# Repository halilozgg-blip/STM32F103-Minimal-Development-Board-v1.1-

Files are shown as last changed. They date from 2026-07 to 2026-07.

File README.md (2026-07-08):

# STM32F103 Minimal Development Board (v1.1)
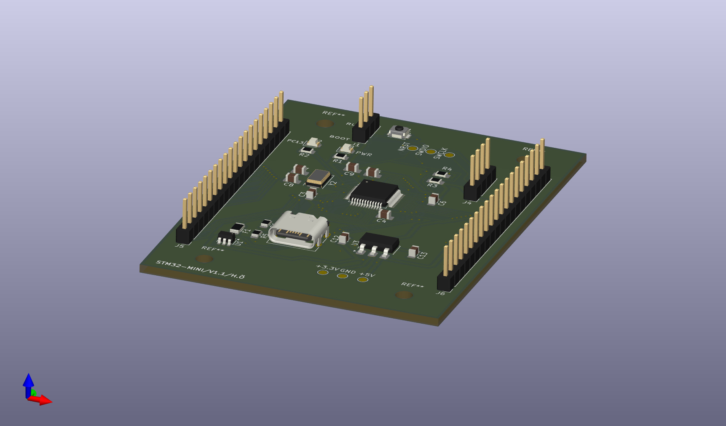
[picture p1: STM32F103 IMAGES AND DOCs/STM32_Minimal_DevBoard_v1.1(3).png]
Board 3D Render




##  Project Overview
This project is a custom-designed **STM32F103C8T6** development board created using **KiCad 9.0**. It provides a compact and reliable hardware platform for embedded software development, rapid prototyping, and educational projects.

The design focuses on clean power distribution, hardware protection, modular architecture, and debugging convenience while following recommended PCB design practices.

##  Design Goals
* **Reliable Hardware:** Design a stable and reusable STM32 development platform.
* **Easy Development:** Provide essential interfaces required for firmware development and debugging.
* **Good PCB Practices:** Follow clean schematic organization and PCB layout guidelines.
* **Open Source:** Make the project easy to understand, reproduce, and modify.

##  Key Features

###  Power & Protection
* **USB Type-C** Power Input.
* **USBLC6-2SC6** TVS diode for ESD protection on USB data lines.
* **500 mA** Resettable PTC Polyfuse for overcurrent protection.
* **AMS1117-3.3V** linear regulator providing a stable 3.3V supply.
* Decoupling capacitors placed according to STM32 hardware design recommendations.

###  Microcontroller Hardware
* **STM32F103C8T6** ARM Cortex-M3 microcontroller.
* External crystal oscillator.
* Hardware reset circuit.
* Pull-down resistor on `BOOT0` for reliable boot configuration.
* **SWD** programming and debugging interface.
* Clearly labeled test points for debugging and measurements.

###  Development Features
* User LED.
* User push button.
* GPIO expansion headers.
* Modular schematic hierarchy for easier maintenance and future expansion.

## 📂 Repository Structure
  ```text
STM32F103_Minimal_Development_Board_v1.1
│
├── HARDWARE/        # KiCad Project, Schematics, and PCB Layout
├── PRODUCTION/     # Gerber Files, Drill Files, and Manufacturing Outputs
└── STM32F103 IMAGES AND DOCS/
    ├── Schematic PDF, PCB Images
    ├── 3D Renders
    └── Project Documentation
  ```
#  Hardware Summary

| Component | Description |
| :--- | :--- |
| **MCU** | STM32F103C8T6 |
| **Core** | ARM Cortex-M3 |
| **Operating Voltage** | 3.3 V |
| **Power Input** | USB Type-C |
| **Debug Interface** | SWD |
| **PCB Design** | KiCad 9.0 |

##  Future Improvements
* USB communication support.
* Additional protection circuitry.
* Boot mode selection jumper.
* CAN interface.
* External SPI Flash & I²C EEPROM.
* Additional status indicators.

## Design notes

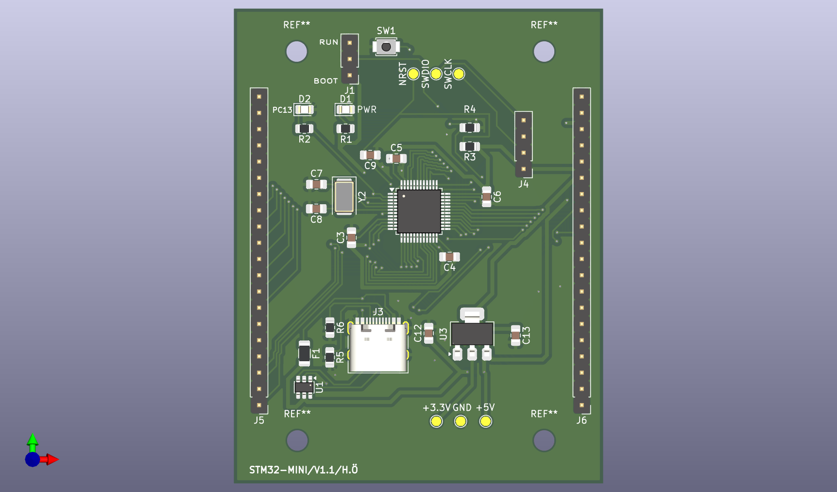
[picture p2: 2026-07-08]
STM32F103 IMAGES AND DOCs/STM32_Minimal_DevBoard_v1.1(1).png

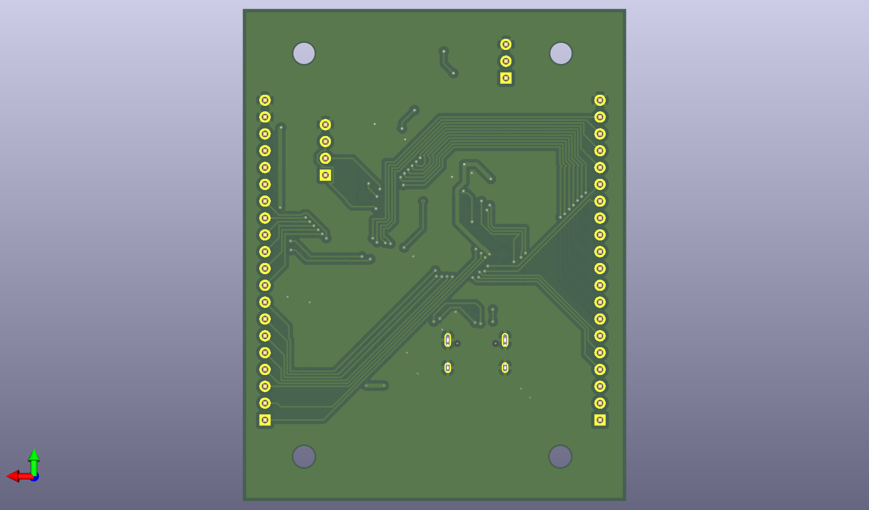
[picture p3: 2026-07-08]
STM32F103 IMAGES AND DOCs/STM32_Minimal_DevBoard_v1.1(2).png

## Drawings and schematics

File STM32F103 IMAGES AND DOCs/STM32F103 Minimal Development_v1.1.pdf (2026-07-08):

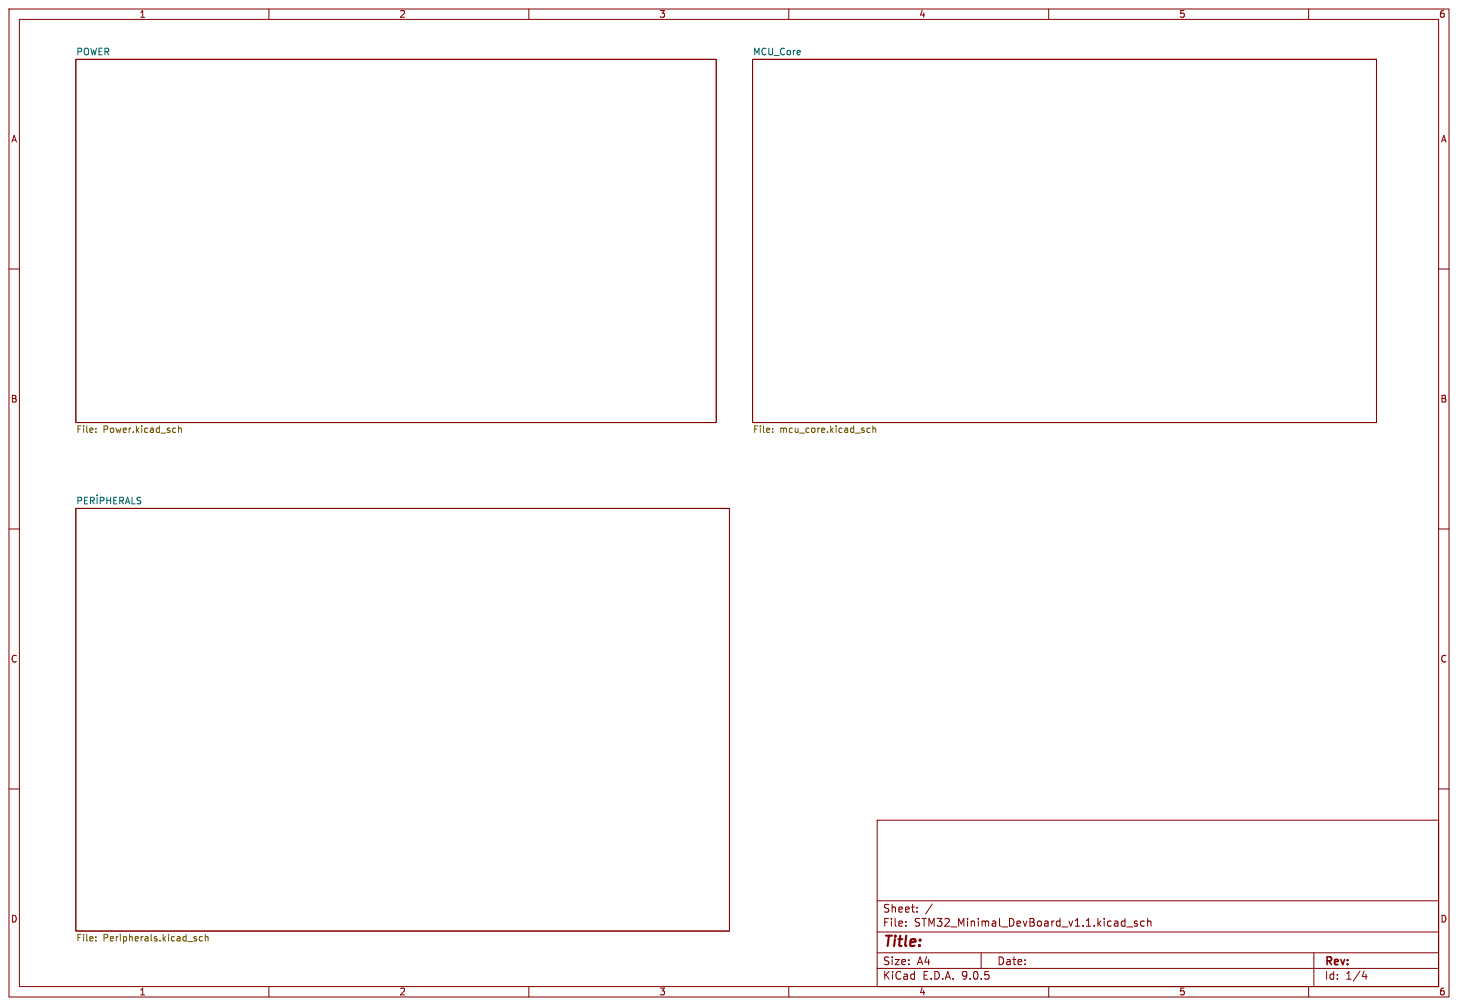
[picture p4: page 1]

Id: 1/4 Title: File: STM32_Minimal_DevBoard_v1.1.kicad_sch Sheet: /

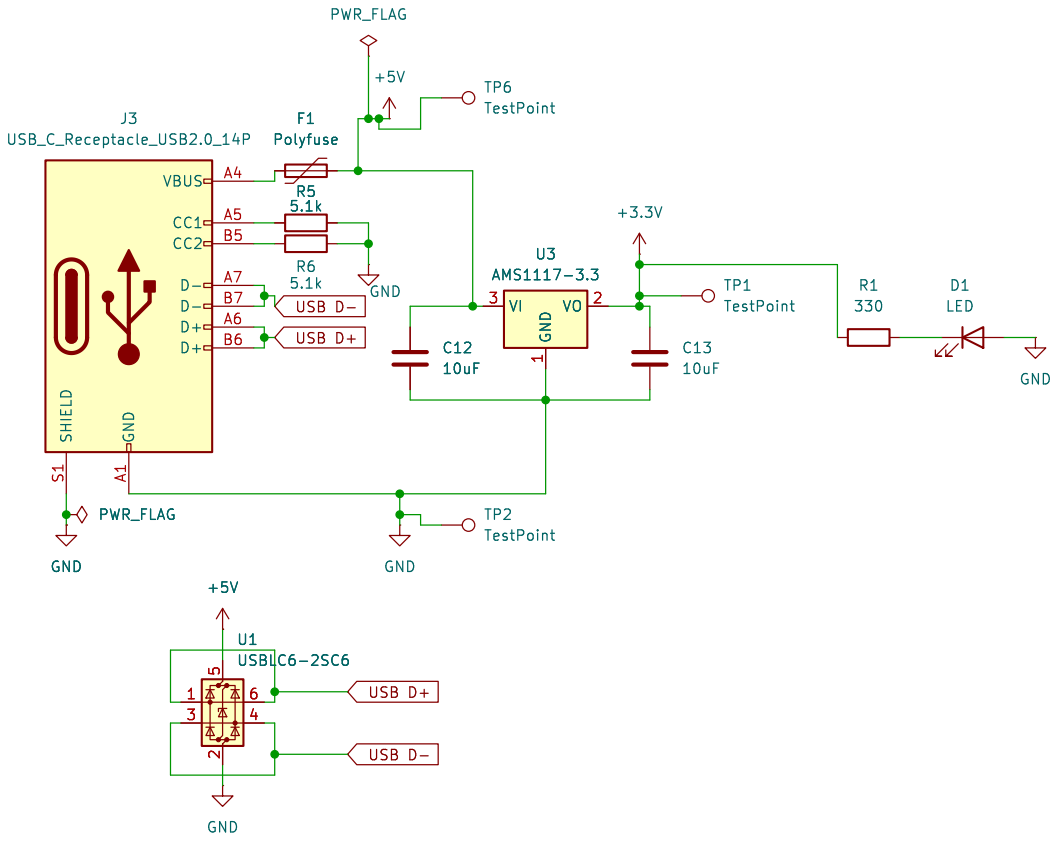
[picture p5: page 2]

330 USB D- USB D+ USB D+ USB D- GND

Id: 2/4 Title: File: Power.kicad_sch Sheet: /POWER/

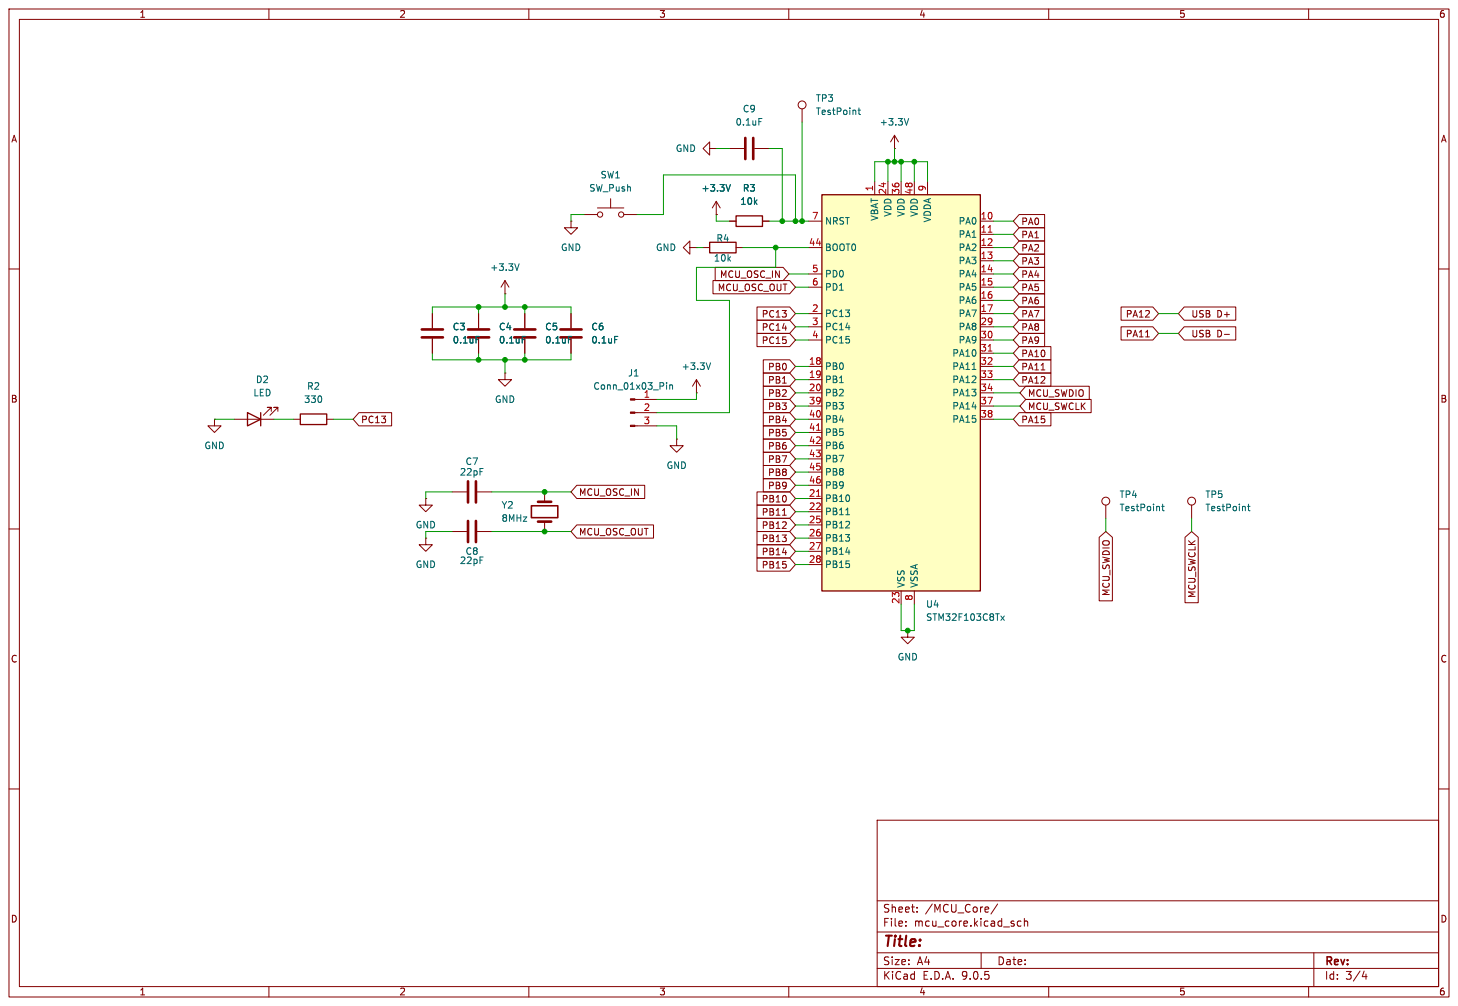
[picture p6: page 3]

1 VDD 24 VDD 36 VSS 23 VDD 48 VSSA

Id: 3/4 Title: File: mcu_core.kicad_sch Sheet: /MCU_Core/

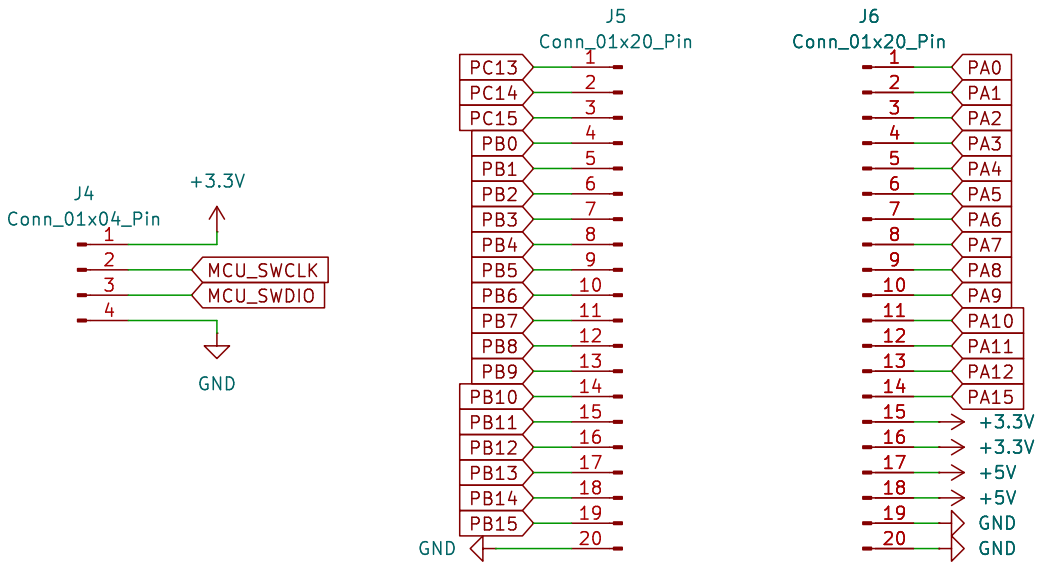
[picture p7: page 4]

Id: 4/4 Title: File: Peripherals.kicad_sch Sheet: þÿ/PER0PHERALS/

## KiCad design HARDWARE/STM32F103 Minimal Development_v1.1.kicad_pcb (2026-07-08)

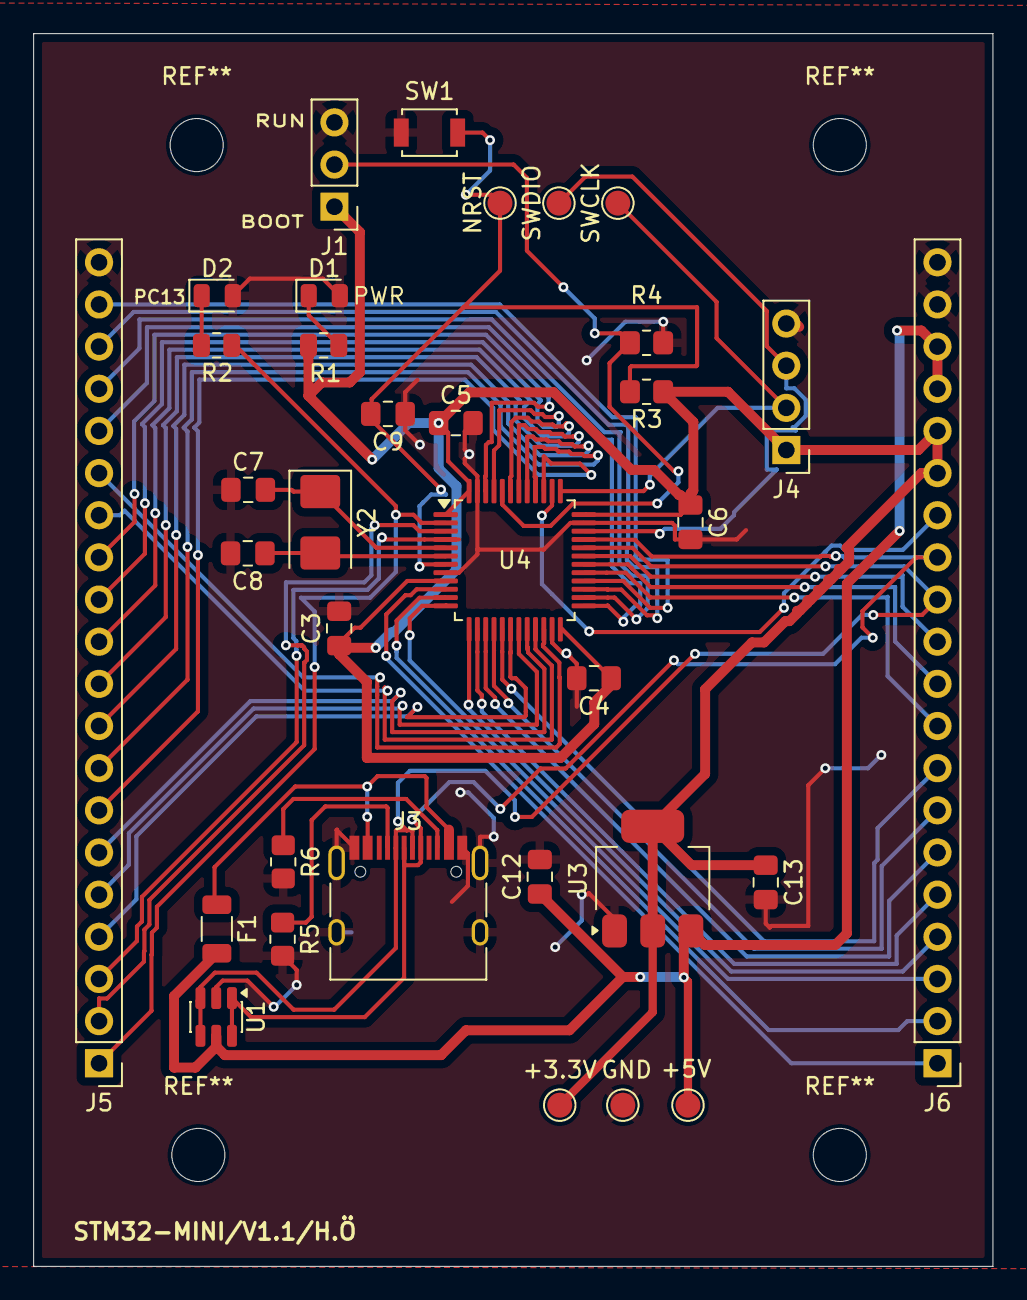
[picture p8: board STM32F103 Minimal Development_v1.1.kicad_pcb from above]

Board: 2 copper layers, 57.8 x 74.3 mm, 34 parts (0 on the bottom side), 47 nets.

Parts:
+3.3V, +5V: TestPoint; TestPoint_Pad_D1.5mm
C3, C4, C5, C6, C9: 0.1uF; C_0805_2012Metric_Pad1.18x1.45mm_HandSolder
C7, C8: 22pF; C_0805_2012Metric_Pad1.18x1.45mm_HandSolder
C12, C13: 10uF; C_0805_2012Metric_Pad1.18x1.45mm_HandSolder
D1, D2: LED; LED_0805_2012Metric
F1: Polyfuse; R_1206_3216Metric
GND: TestPoint; TestPoint_Pad_D1.5mm
J1: Conn_01x03_Pin; PinHeader_1x03_P2.54mm_Vertical
J3: USB_C_Receptacle_USB2.0_14P; USB_C_Receptacle_HRO_TYPE-C-31-M-12
J4: Conn_01x04_Pin; PinHeader_1x04_P2.54mm_Vertical
J5, J6: Conn_01x20_Pin; PinHeader_1x20_P2.54mm_Vertical
NRST: TestPoint; TestPoint_Pad_D1.5mm
R1, R2: 330; R_0805_2012Metric
R3, R4: 10k; R_0805_2012Metric_Pad1.20x1.40mm_HandSolder
R5, R6: 5.1k; R_0805_2012Metric_Pad1.20x1.40mm_HandSolder
SW1: SW_Push; SW_SPST_B3U-1000P
SWCLK: TestPoint; TestPoint_Pad_D1.5mm
SWDIO: TestPoint; TestPoint_Pad_D1.5mm
U1: USBLC6-2SC6; SOT-23-6
U3: AMS1117-3.3; SOT-223-3_TabPin2
U4: STM32F103C8Tx; LQFP-48_7x7mm_P0.5mm
Y2: 8MHz; Crystal_SMD_5032-2Pin_5.0x3.2mm

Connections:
USB D+: J3.A6 (D+), J3.B6 (D+), J6.13, U1.1 (I/O1), U1.6 (I/O1), U4.33 (PA12)
USB D-: J3.A7 (D-), J3.B7 (D-), J6.12, U1.3 (I/O2), U1.4 (I/O2), U4.32 (PA11)
+3.3V: +3.3V.1, C3.1, C4.1, C5.1, C6.1, C13.1, J1.1, J4.1, J6.15, J6.16, R1.1, R3.1, U3.2 (VO), U4.1 (VBAT), U4.9 (VDDA), U4.24 (VDD), U4.36 (VDD), U4.48 (VDD)
+5V: +5V.1, C12.1, F1.2, J6.17, J6.18, U1.5 (VBUS), U3.3 (VI)
GND: C3.2, C4.2, C5.2, C6.2, C7.1, C8.2, C9.1, C12.2, C13.2, D1.2 (A), D2.2 (A), GND.1, J1.3, J3.A1 (GND), J3.A12 (GND), J3.B1 (GND), J3.B12 (GND), J3.S1 (SHIELD), J4.4, J5.20, J6.19, J6.20, R4.1, R5.2, R6.2, SW1.1, U1.2 (GND), U3.1 (GND), U4.8 (VSSA), U4.23 (VSS), U4.35 (VSS), U4.47 (VSS)
MCU_OSC_IN: C7.2, U4.5 (PD0), Y2.1
MCU_OSC_OUT: C8.1, U4.6 (PD1), Y2.2
MCU_SWCLK: J4.2, SWCLK.1, U4.37 (PA14)
MCU_SWDIO: J4.3, SWDIO.1, U4.34 (PA13)
unnamed: D1.1 (K), R1.2
unnamed: D2.1 (K), R2.1
unnamed: F1.1, J3.A4 (VBUS), J3.A9 (VBUS), J3.B4 (VBUS), J3.B9 (VBUS)
unnamed: J1.2, R4.2, U4.44 (BOOT0)
unnamed: J3.A5 (CC1), R5.1
unnamed: J3.B5 (CC2), R6.1
unnamed: C9.2, NRST.1, R3.2, SW1.2, U4.7 (NRST)
PA0: J6.1, U4.10 (PA0)
PA1: J6.2, U4.11 (PA1)
PA2: J6.3, U4.12 (PA2)
PA3: J6.4, U4.13 (PA3)
PA4: J6.5, U4.14 (PA4)
PA5: J6.6, U4.15 (PA5)
PA6: J6.7, U4.16 (PA6)
PA7: J6.8, U4.17 (PA7)
PA8: J6.9, U4.29 (PA8)
PA9: J6.10, U4.30 (PA9)
PA10: J6.11, U4.31 (PA10)
PA15: J6.14, U4.38 (PA15)
PB0: J5.4, U4.18 (PB0)
PB1: J5.5, U4.19 (PB1)
PB2: J5.6, U4.20 (PB2)
PB3: J5.7, U4.39 (PB3)
PB4: J5.8, U4.40 (PB4)
PB5: J5.9, U4.41 (PB5)
PB6: J5.10, U4.42 (PB6)
PB7: J5.11, U4.43 (PB7)
PB8: J5.12, U4.45 (PB8)
PB9: J5.13, U4.46 (PB9)
PB10: J5.14, U4.21 (PB10)
PB11: J5.15, U4.22 (PB11)
PB12: J5.16, U4.25 (PB12)
PB13: J5.17, U4.26 (PB13)
PB14: J5.18, U4.27 (PB14)
PB15: J5.19, U4.28 (PB15)
PC13: J5.1, R2.2, U4.2 (PC13)
PC14: J5.2, U4.3 (PC14)
PC15: J5.3, U4.4 (PC15)
